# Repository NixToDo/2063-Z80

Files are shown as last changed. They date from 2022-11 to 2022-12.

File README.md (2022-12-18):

# Retro Z80 CPU Board

This project is a small changed copy of the great design from John Winans. I have added a J3A1 connector to get the IORQ_50, IORQ_60 and SIO_IEO from the PCB.

This project was designed to run CP/M 2.2 from an SD card.  It should be an attainable goal for anyone that can solder through-hole parts to assemble it. Note that J10 is an optional header that allows a Sparkfun SD card breakout board [DEV-13743](https://www.digikey.com/en/products/detail/sparkfun-electronics/DEV-13743/5881845) to used instead of soldering on the surface-mount SD socket part.

## Where to get Boards & Software

* You can order boards from any prototype PCB vendor.  For example, I show how you can order these boards from [JLCPCB](https://jlcpcb.com/) or [OSHPark](https://oshpark.com/) by uploading the gerber files found in the releases of this and the flash programmer projects as shown in this [Z80 Retro! - How To Order PC Boards](https://youtu.be/AUg_sbPnzn0) video on YouTube.
  - Gerber files for the CPU board: [2063-Z80-v3](https://github.com/johnwinans/2063-Z80/releases/download/v3/2063-Z80-gerbers.zip)
  - Gerber files for the FLASH programmer: [2065-Z80-programmer-v2](https://github.com/johnwinans/2065-Z80-programmer/releases/download/v2.0/2065-Z80-programmer-gerbers.zip) (This is used with a Raspberry PI to program the FLASH chip on the CPU board.)

* Software for this project can be found in my [2063-Z80-cpm](https://github.com/johnwinans/2063-Z80-cpm) repo.

* Note that the [FLASH programmer](https://github.com/johnwinans/2065-Z80-programmer) has been designed to work with a Raspberry PI in the event that you don't already own such programmer.  This companion programmer PCB should cost about $2 more when it is ordered at the same time as the CPU board from JLCPCB or other similar proto-board shops as shown in the [Z80 Retro! - How To Order PC Boards](https://youtu.be/AUg_sbPnzn0) video on YouTube.

## Links to Related Material

* A youtube playlist discussing this project and how to build your own can be found in [John's Basement](https://www.youtube.com/watch?v=oekucjDcNbA&list=PL3by7evD3F51Cf9QnsAEdgSQ4cz7HQZX5)
* A PDF version of the schematic can be found [here](2063-Z80.pdf).
* Here is the as-built [BOM](2063-Z80.md) with links to the datasheets for all the parts.
* Here is another [BOM](2063-Z80-sockets.md) with links to sockets for the chips.
* To configure a new PI for use with this programmer board as well as to develop Z80 code 
for the Z80 Retro board, see this [PI Setup Guide](https://github.com/johnwinans/raspberry-pi-install)
* More software for this project will be added as it evolves.

## Links to Related Datasheets Seen On YouTube

* [Z80 Datasheet PS0178](https://www.zilog.com/docs/z80/ps0178.pdf) with detailed timing diagrams.
* [Z80 User Manual UM0080](http://www.zilog.com/docs/z80/um0080.pdf) with detailed descriptions of each instruction.
* [Z80 CPU Peripherals User Manual UM0081](http://www.zilog.com/docs/z80/um0081.pdf) discusses the CTC and SIO.
* [Z80 Family Product Specifications Handbook - 1984](http://www.bitsavers.org/components/zilog/z80/Z80_Family_Product_Specifications_Handbook_Feb84.pdf) has nicer pictures of the SIO registers.
* [Wikipedia UART Article](https://en.wikipedia.org/wiki/Universal_asynchronous_receiver-transmitter)
* [AY-3-1015D UART Datasheet](https://rocelec.widen.net/view/pdf/bvesdj0cqf/GSIIS01845-1.pdf) (Has a discussion of the 16X bit-rate clock with diagrams etc. applicable to all UARTs.)

## Serial Port Cable Parts

* [How to make IDC cables](https://youtu.be/gZ420Z-8HuU) for the serial ports.
* [IDC 2x5 connectors](https://www.amazon.com/gp/product/B07S1NFG4S)
* [IDC D-SUB 9-pin connectors (Digikey)](https://www.digikey.com/en/products/detail/assmann-wsw-components/A-DSF-09LPIII-Z/924263)
* [IDC D-SUB 9-pin connectors (Amazon)](https://www.amazon.com/Uxcell-a15030600ux0494-Female-Connector-Ribbon/dp/B00YM41NTW)

## Parallel Port Cable Parts

* [IDC 2x13 connectors](https://www.amazon.com/gp/product/B07RXK96GV)
* [IDC D-SUB 25-pin connectors (Digikey)](https://www.digikey.com/en/products/detail/amphenol-icc-commercial-products/L17DBFRA25S/1972210)
* [IDC D-SUB 25-pin connectors (Amazon)](https://www.amazon.com/Fielect-Female-Adapter-Connector-Ribbon/dp/B082GMDNTS)

## Ribbon Cable

* [40-conductor (Amazon)](https://www.amazon.com/Eowpower-40Pin-40Way-Rainbow-Ribbon/dp/B079KQ6K3Y) - peel off a
 26-pin strip and a 10-pin strip to make one parallel and one serial cable (cut the 10-pin strip in half length-wise to make two serial cables.

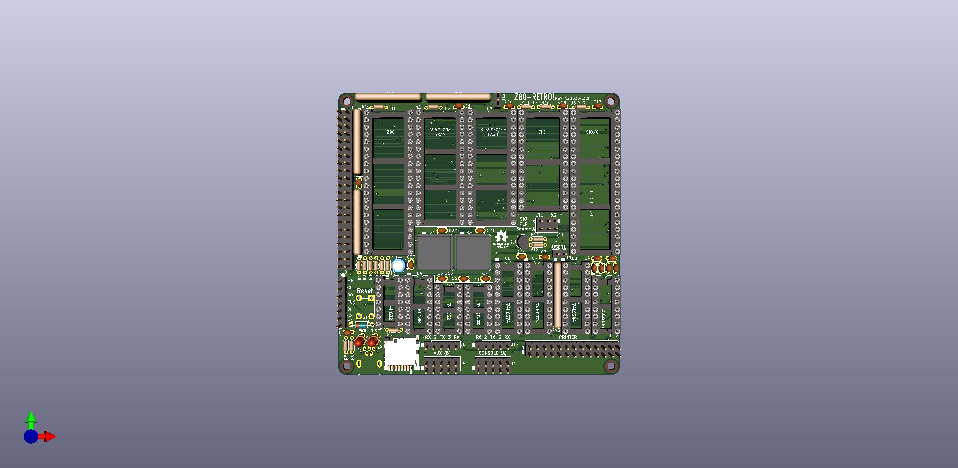
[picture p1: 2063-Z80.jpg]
PC Board Image Retro Z80 CPU Board Rev 2


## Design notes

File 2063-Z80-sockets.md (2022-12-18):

## IC Sockets

You can buy fancy expensive ones, or you can buy cheap ones.
I used the cheap ones.  

Alternately, you can just solder the chips into the PCB.

As a tinkerer, the thing that is wrong with that is that it makes it very hard to 
recycle/repurpose the chips for something else in the future.  And with the 2021
chip-shortage in full-force on as I type this, being able to recycle chips is 
VERY appealing!

Be honest with yourself before sinking more money into sockets than the cost of the chips 
that go into them.  I expect the cheap ones to last for at least a decade or two.  Cheap
sockets in my hobby projects from 30 years ago are still doing fine.

Gold plating is better than tin.  Machined pins (see the oscillator sockets) are better than
stamped spring-metal pins. 

Ref | Qty | Value | Digikey | Datasheet | Description
----|-----|-------|---------|-----------|------------
U1,U5 | 2 | Socket | AE10008-ND | http://www.assmann-wsw.com/uploads/datasheets/ASS_0810_CO.pdf | DIP-40
U2,U3 | 2 | Socket | 2057-ICS-632-T-ND | https://app.adam-tech.com/products/download/data_sheet/199581/ics-6xx-t-data-sheet.pdf | DIP-32
U4 | 1 | Socket | 2057-ICS-628-T-ND | https://app.adam-tech.com/products/download/data_sheet/199581/ics-6xx-t-data-sheet.pdf | DIP-28
U10,U13,U11 | 3 | Socket | 2057-ICS-314-T-ND | https://app.adam-tech.com/products/download/data_sheet/199582/ics-3xx-t-data-sheet.pdf | DIP-14
U9,U12 | 2 | Socket | 2057-ICS-316-T-ND | https://app.adam-tech.com/products/download/data_sheet/199582/ics-3xx-t-data-sheet.pdf | DIP-16
U6,U7,U8 | 3 | Socket | 2057-ICS-320-T-ND | https://app.adam-tech.com/products/download/data_sheet/199582/ics-3xx-t-data-sheet.pdf | DIP-20

# Sockets for the Oscillators

Metal can oscillators have wires for pins.  In my experience they tend to sit loosely in 
regular sockets and do better in machined-pin sockets.

For these 4-pin parts you have two options.  Either order a relatively expensive pair of 
sockets ready to solder in as-is or order a pair with extra pins and remove the ones you don't
want and then solder in. 

I went the latter route because I already had several 8-pin sockets on hand.

To remove the extra pins from the fully loaded sockets, use a small pliers to grab the pins 
to be removed from the bottom of the socket and push them out the top.

Look at the photos of each type and you'll see what I mean.

Ref | Qty | Value | Digikey | Datasheet | Description
----|-----|-------|---------|-----------|------------
X1,X2 | 2 | Socket | ED90427-ND | https://www.mill-max.com/catalog/download/2017-11:134.pdf | OSC-4 (a whopping $1.50 each!)
X1,X2 | 2 | Socket | AE10011-ND | http://www.assmann-wsw.com/uploads/datasheets/ASS_4852_CO.pdf | DIP-8 ($.50 each)

## Shorting Blocks

These are for selecting the clock sources for the SIO, user jumper, and 
RS-232 TX/RX pin number selection.

Ref | Qty | Value | Digikey | Datasheet | Description
----|-----|-------|---------|-----------|------------
J11,J9,J1,J8 | 7 | S9337-ND | https://s3.amazonaws.com/catalogspreads-pdf/PAGE128-129%20.100%20JUMPER.pdf | Shorting Block | Shorting Jumper

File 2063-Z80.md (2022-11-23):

# 2063-Z80.sch

## Wed Dec  1 16:48:16 2021

## Eeschema 5.1.5+dfsg1-2build2

## Component Count:84

Ref | Qty | Value | Digikey | Datasheet | Description
----|-----|-------|---------|-----------|------------
Z5U RM2,5 100n 50V             C1, C2, C3, C4, C5, C6, C7, C8, C9, C10, C11, C12, C13, C14, C15, C16, C21, C22, C23 | 19 | .1 | 399-9859-1-ND | https://api.kemet.com/component-edge/download/specsheet/C315C104M5U5TA7303.pdf | Unpolarized capacitor, small symbol
X7R 0805 100n 50V              C17 | 1 | .1 | 1276-1935-1-ND | https://www.mouser.com/datasheet/2/585/MLCC-1837944.pdf | Unpolarized capacitor, small symbol
X5R 0805 10µ 6,3V              C18 | 1 | 10uF | 1276-1298-1-ND | https://media.digikey.com/pdf/Data%20Sheets/Samsung%20PDFs/CL21A106MQFNNNE_Spec.pdf | Polarized capacitor, small US symbol
    RM2,54 10µ 25V                C19 | 1 | 10uF | P975-ND | https://industrial.panasonic.com/cdbs/www-data/pdf/RDF0000/ABA0000C1059.pdf | Polarized capacitor, small US symbol
X7R RM2,54 0,47µ 50V            C20 | 1 | .47 | 399-14039-1-ND | https://api.kemet.com/component-edge/download/datasheet/C315C474K5R5TA7303.pdf | Unpolarized capacitor, small symbol
X7R 0805 100n 50V              C24 | 1 | .1 | 1276-1935-1-ND | https://www.mouser.com/datasheet/2/585/MLCC-1837944.pdf | Unpolarized capacitor, small symbol
3mm LED rot 20mA               D1, D2 | 2 | LED_ALT | 1080-1122-ND | https://media.digikey.com/PDF/Data%20Sheets/Everlight%20PDFs/ds300034.pdf | Light emitting diode, filled shape
1N4148                         D3 | 1 | 1N914 | 1N4148FSCT-ND | http://www.vishay.com/docs/85622/1n914.pdf | 100V 0.3A Small Signal Fast Switching Diode, DO-35
                               H1, H2, H3, H4 | 4 | MountingHole |  |  | Mounting Hole without connection
Pinheader 1x5 pol              J1, J8 | 2 | Conn_01x05 | S1211EC-05-ND | https://media.digikey.com/PDF/Data%20Sheets/Sullins%20PDFs/xRxCzzzSxxN-RC_ST_11635-B.pdf | Generic connector, single row, 01x05, script generated (kicad-library-utils/schlib/autogen/connector/)
Micro SDcard DM3D-SF(41)       J2 | 1 | DM3D-SF(41) | H126097CT-ND (alternate: 114-00841-68-1-ND) | https://www.hirose.com/product/document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 | Micro SD Card Socket with card detection pins
Pinheader 2x20 pol             J3 | 1 | Conn_02x20 | S2011EC-20-ND | https://drawings-pdf.s3.amazonaws.com/11636.pdf | Generic connector, double row, 02x20, counter clockwise pin numbering scheme (similar to DIP packge numbering), script generated (kicad-library-utils/schlib/autogen/connector/)
Pinheader 2x5 pol              J4, J5 | 2 | Conn_02x05 | 1849-1002-ND |  | Generic connector, double row, 02x05, odd/even pin numbering scheme (row 1 odd numbers, row 2 even numbers), script generated (kicad-library-utils/schlib/autogen/connector/)
Mini USB Buchse 2172034-1      J6 | 1 | 0548190519 | A135698-ND | https://www.molex.com/pdm_docs/sd/548190519_sd.pdf | CONN RCPT USB2.0 MINI B 5P R/A
Pinheader 2x13 pol             J7 | 1 | Conn_02x13 | S2011EC-13-ND | https://drawings-pdf.s3.amazonaws.com/11636.pdf | Generic connector, double row, 02x13, top/bottom pin numbering scheme (row 1: 1...pins_per_row, row2: pins_per_row+1 ... num_pins), script generated (kicad-library-utils/schlib/autogen/connector/)
Pinheader 1x2 pol              J9, J12 | 2 | Conn_01x02 | S1011EC-02-ND | https://media.digikey.com/PDF/Data%20Sheets/Sullins%20PDFs/xRxCzzzSxxN-RC_ST_11635-B.pdf | Generic connector, single row, 01x02, script generated (kicad-library-utils/schlib/autogen/connector/)
Pinheader 1x7 pol              J10 | 1 | Conn_01x07 | S1011EC-07-ND | https://media.digikey.com/PDF/Data%20Sheets/Sullins%20PDFs/xRxCzzzSxxN-RC_ST_11635-B.pdf | Generic connector, single row, 01x07, script generated (kicad-library-utils/schlib/autogen/connector/)
Pinheader 2x3 pol              J11 | 1 | Conn_02x03 | 2057-PH2-06-UA-ND | https://app.adam-tech.com/products/download/data_sheet/202065/ph2-xx-ua-data-sheet.pdf | Generic connector, double row, 02x03, odd/even pin numbering scheme (row 1 odd numbers, row 2 even numbers), script generated (kicad-library-utils/schlib/autogen/connector/)
                               LOGO1 | 1 | OSHW_Logo |  |  | Open Hardware logo, small
                               LOGO2 | 1 | OSHW_Logo |  |  | Open Hardware logo, small
PN2222A                        Q1 | 1 | PN2222 | 1514-PN2222APBFREE-ND | https://my.centralsemi.com/datasheets/PN2221-2222A.PDF | NPN transistor, emitter/base/collector
2,7k 5% 1/8W axial             R1, R3, R5 | 3 | 2K7 | CF18JT2K70CT-ND | https://www.seielect.com/catalog/sei-cf_cfm.pdf | Resistor
4,7k 5% 1/8W axial             R2, R4, R6 | 3 | 4K7 | CF18JT4K70CT-ND | https://www.seielect.com/catalog/sei-cf_cfm.pdf | Resistor
10k 5% 1/8W axial              R7, R10, R13, R14 | 4 | 10K | CF18JT10K0CT-ND | https://www.seielect.com/catalog/sei-cf_cfm.pdf | Resistor
680 5% 1/8W axial              R8, R9 | 2 | 680 | CF18JT680RCT-ND‎ | https://www.seielect.com/catalog/sei-cf_cfm.pdf | Resistor
1k 5% 1/8W axial               R11, R12 | 2 | 1K | CF18JT1K00CT-ND‎ | https://www.seielect.com/catalog/sei-cf_cfm.pdf | Resistor
120 5% 1/8W axial              R15, R16 | 2 | 120 | CF18JT120RCT-ND | https://www.seielect.com/catalog/sei-cf_cfm.pdf | Resistor
10k SIL 8R                     RN1, RN2, RN3, RN4, RN5 | 5 | 10K | 4609X-101-103LF-ND‎ | https://www.bourns.com/docs/Product-Datasheets/4600x.pdf | 8 resistor network, star topology, bussed resistors, small symbol
Taster FSM4JH                  S1 | 1 | 1825910-6 | 450-1650-ND | https://www.te.com/commerce/DocumentDelivery/DDEController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 | SWITCH TACTILE SPST-NO 0.05A 24V
Z84C0010PEG                    U1 | 1 | Z80-CPU | 269-3898-ND | https://www.zilog.com/manage_directlink.php?filepath=docs/z80/um0080 | 8-bit General Purpose Microprocessor, DIP-40
AS6C4008-55PCN                 U2 | 1 | AS6C4008-55PCN | 1450-1178-5-ND‎ | https://www.alliancememory.com/wp-content/uploads/pdf/AS6C4008.pdf | 512K x 8 Low Power CMOS RAM, DIP-32
Vorhanden                      U3 | 1 | SST39SF010 | SST39SF010A-70-4C-PHE-ND‎ | https://ww1.microchip.com/downloads/en/DeviceDoc/20005022C.pdf | Silicon Storage Technology (SSF) 128k x 8 Flash ROM
Z84C3010PEG                    U4 | 1 | Z80-CTC | 269-3914-ND | http://www.zilog.com/docs/z80/ps0181.pdf | Z80 CTC DIP-28
Z84C4010PEG                    U5 | 1 | Z80-SIO-0 | 269-5062-ND‎ | http://www.zilog.com/docs/z80/ps0183.pdf | SCC Serial Communication Controller, DIP-40
74HC374                        U6, U7 | 2 | 74HC374 | 296-12806-5-ND | https://www.ti.com/lit/ds/symlink/cd74hct374.pdf | 8-bit Register, 3-state outputs
74LS244                        U8 | 1 | 74LS244 | 296-36148-5-ND | https://www.ti.com/lit/ds/symlink/sn74ls241.pdf | 8-bit Bus Buffer 3-State outputs
74HC138                        U9 | 1 | 74HC138 | 296-SN74HC138AN-ND | https://www.ti.com/lit/ds/symlink/sn54hc138.pdf | Decoder 3 to 8 active low outputs
74HC32                         U10, U13 | 2 | 74HC32 | 296-12803-5-ND | https://www.ti.com/lit/ds/symlink/cd74hc32.pdf | Quad 2-input OR
74HCT132                       U11 | 1 | 74HCT132 | 296-2090-5-ND | https://www.ti.com/lit/ds/symlink/cd74hc132.pdf | Quad 2-input NAND Schmitt trigger
ICL3232CPZ alt: MAX3232        U12 | 1 | ICL3232CPZ | ICL3232CPZ-ND‎ | https://www.renesas.com/us/en/document/dst/icl3221-icl3222-icl3223-icl3232-icl3241-icl3243-datasheet | 3.0V to 5.5V, Low-Power, up to 1Mbps, True RS-232 Transceivers Using Four 0.1μF External Capacitors
NCP1117ST33T3G                 U20 | 1 | LM1117-3.3 | NCP1117ST33T3GOSCT-ND | https://www.onsemi.com/pdf/datasheet/ncp1117-d.pdf | 800mA Low-Dropout Linear Regulator, 1.8V fixed output, TO-220/TO-252/TO-263/SOT-223
ACH-10.000MHZ-EK               X1 | 1 | ACH-10.000MHZ-EK | 535-9167-5-ND | https://abracon.com/Oscillators/ACH.pdf | Crystal Clock Oscillator, DIP8-style metal package
ECS-2100A-018                  X2 | 1 | ECS-2100A-018 | XC231-ND‎ | https://ecsxetal.com/store/pdf/ecs_2100.pdf | Crystal Clock Oscillator, DIP8-style metal package

40 Pin                         U1,U5 | 2 | Socket | AE10008-ND | http://www.assmann-wsw.com/uploads/datasheets/ASS_0810_CO.pdf | DIP-40
32 Pin                         U2,U3 | 2 | Socket | 2057-ICS-632-T-ND | https://app.adam-tech.com/products/download/data_sheet/199581/ics-6xx-t-data-sheet.pdf | DIP-32
28 Pin                         U4 | 1 | Socket | 2057-ICS-628-T-ND | https://app.adam-tech.com/products/download/data_sheet/199581/ics-6xx-t-data-sheet.pdf | DIP-28
14 Pin                         U10,U13,U11 | 3 | Socket | 2057-ICS-314-T-ND | https://app.adam-tech.com/products/download/data_sheet/199582/ics-3xx-t-data-sheet.pdf | DIP-14
16 Pin                         U9,U12 | 2 | Socket | 2057-ICS-316-T-ND | https://app.adam-tech.com/products/download/data_sheet/199582/ics-3xx-t-data-sheet.pdf | DIP-16
20 Pin                         U6,U7,U8 | 3 | Socket | 2057-ICS-320-T-ND | https://app.adam-tech.com/products/download/data_sheet/199582/ics-3xx-t-data-sheet.pdf | DIP-20

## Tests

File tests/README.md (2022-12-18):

# Basic test applications for the Z80 Retro board.

These applications require the use of `z80asm`.  You can install it like this:

	sudo apt install z80asm

Assemble these test applications like this:

	make world

Download them into the FLASH by using the `flash` programming application in the 
[2065-Z80-programmer](https://github.com/johnwinans/2065-Z80-programmer/tree/master/pi) 
project in github.  If you cloned the 2065-Z80-programmer project into your
home directory and built it on your PI then you can program these files like this:

	~/2065-Z80-programmer/pi/flash < blinky1.bin

## Test Programs

### blinky1.asm
Flash the SD card select LED.  This runs entirely from the FLASH (does not use SRAM).

### blinky2.asm
Flash the SD card select LED.  This copies itself from the FLASH into the SRAM and then runs from there.

### blinky3.asm
Flash the SD card select LED and at the same time, count on the printer port data lines.

### hello_sio1.asm
Test the SIO ports in polled mode.

### hello_sio2.asm
Test the SIO ports in IRQ mode.

### hello_ctc2.asm
Test the CTC with IRQs and print an 'uptime' counter using the SIO.

## bank_select.asm
Test the SRAM blank select logic by padding and dumping regions of memory in different banks.

## hello_lpt.asm
Test the printer port by priting a 'hello world' type message.

## hello_lpt2.asm
Test the printer port by priting gaudy banners.

## io.asm
Equates for the IO ports on the Z80 Retro! board.

## sio.asm
Simple driver for the SIO.

## hexdump.asm
A library to print a memory hex dump.

## ctc.asm
Simple driver for the CTC.

## lpt.asm
Simple driver for the printer.

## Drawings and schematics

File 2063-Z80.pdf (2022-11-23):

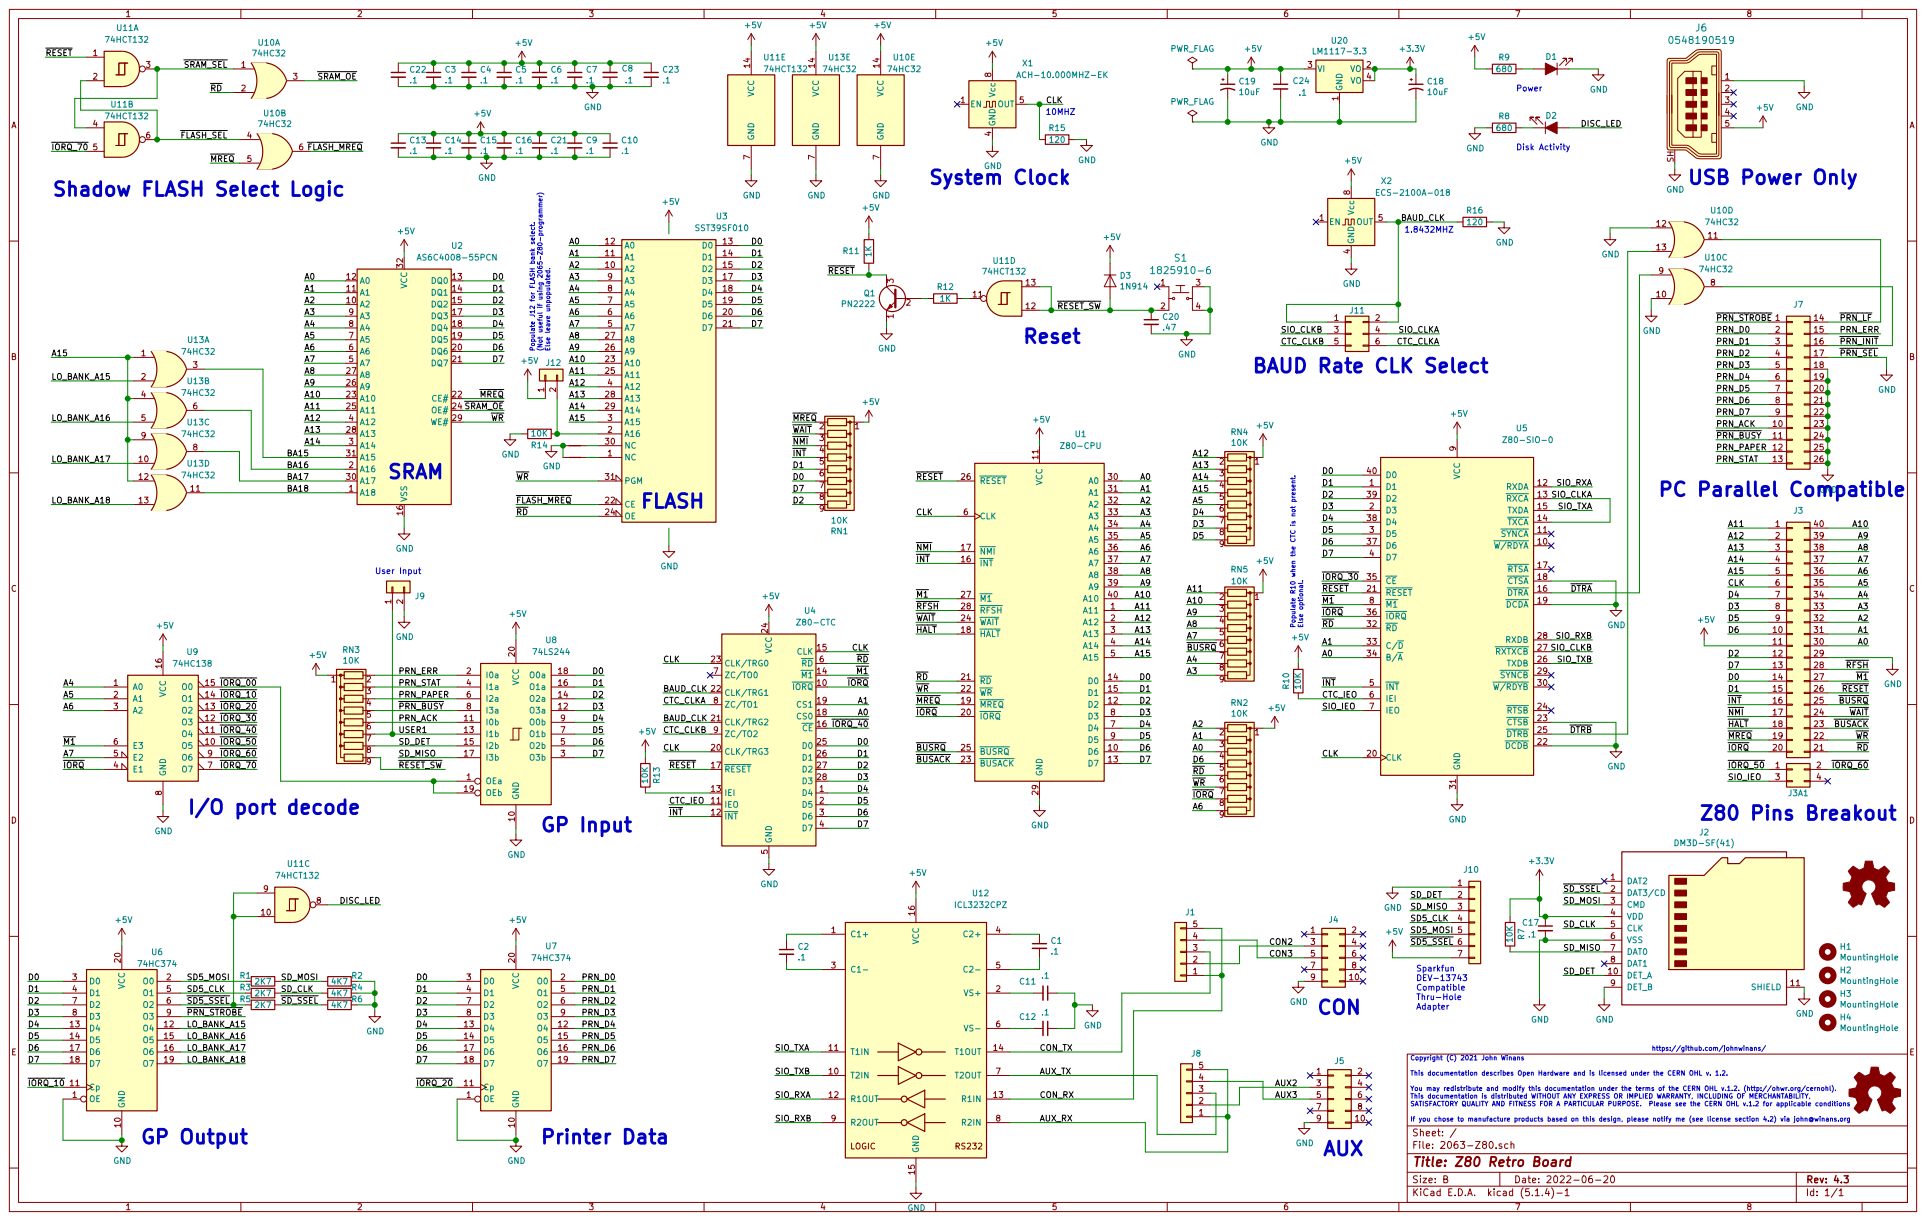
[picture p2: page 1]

If you chose to manufacture products based on this design, please notify me (see license section 4.2) via john@winans.org USB Power Only

Shadow FLASH Select Logic

Disk Activity Populate R10 when the CTC is not present. Else optional.

BAUD Rate CLK Select

5 | PRN_ACK

Sparkfun DEV-13743 Compatible Thru-Hole Adapter

https://github.com/johnwinans/ GP Output

Copyright (C) 2021 John Winans This documentation describes Open Hardware and is licensed under the CERN OHL v. 1.2. You may redistribute and modify this documentation under the terms of the CERN OHL v.1.2. (http://ohwr.org/cernohl). This documentation is distributed WITHOUT ANY EXPRESS OR IMPLIED WARRANTY, INCLUDING OF MERCHANTABILITY, SATISFACTORY QUALITY AND FITNESS FOR A PARTICULAR PURPOSE. Please see the CERN OHL v.1.2 for applicable conditions

File: 2063-Z80.sch Sheet: /
Id: 1/1 Title: Z80 Retro Board

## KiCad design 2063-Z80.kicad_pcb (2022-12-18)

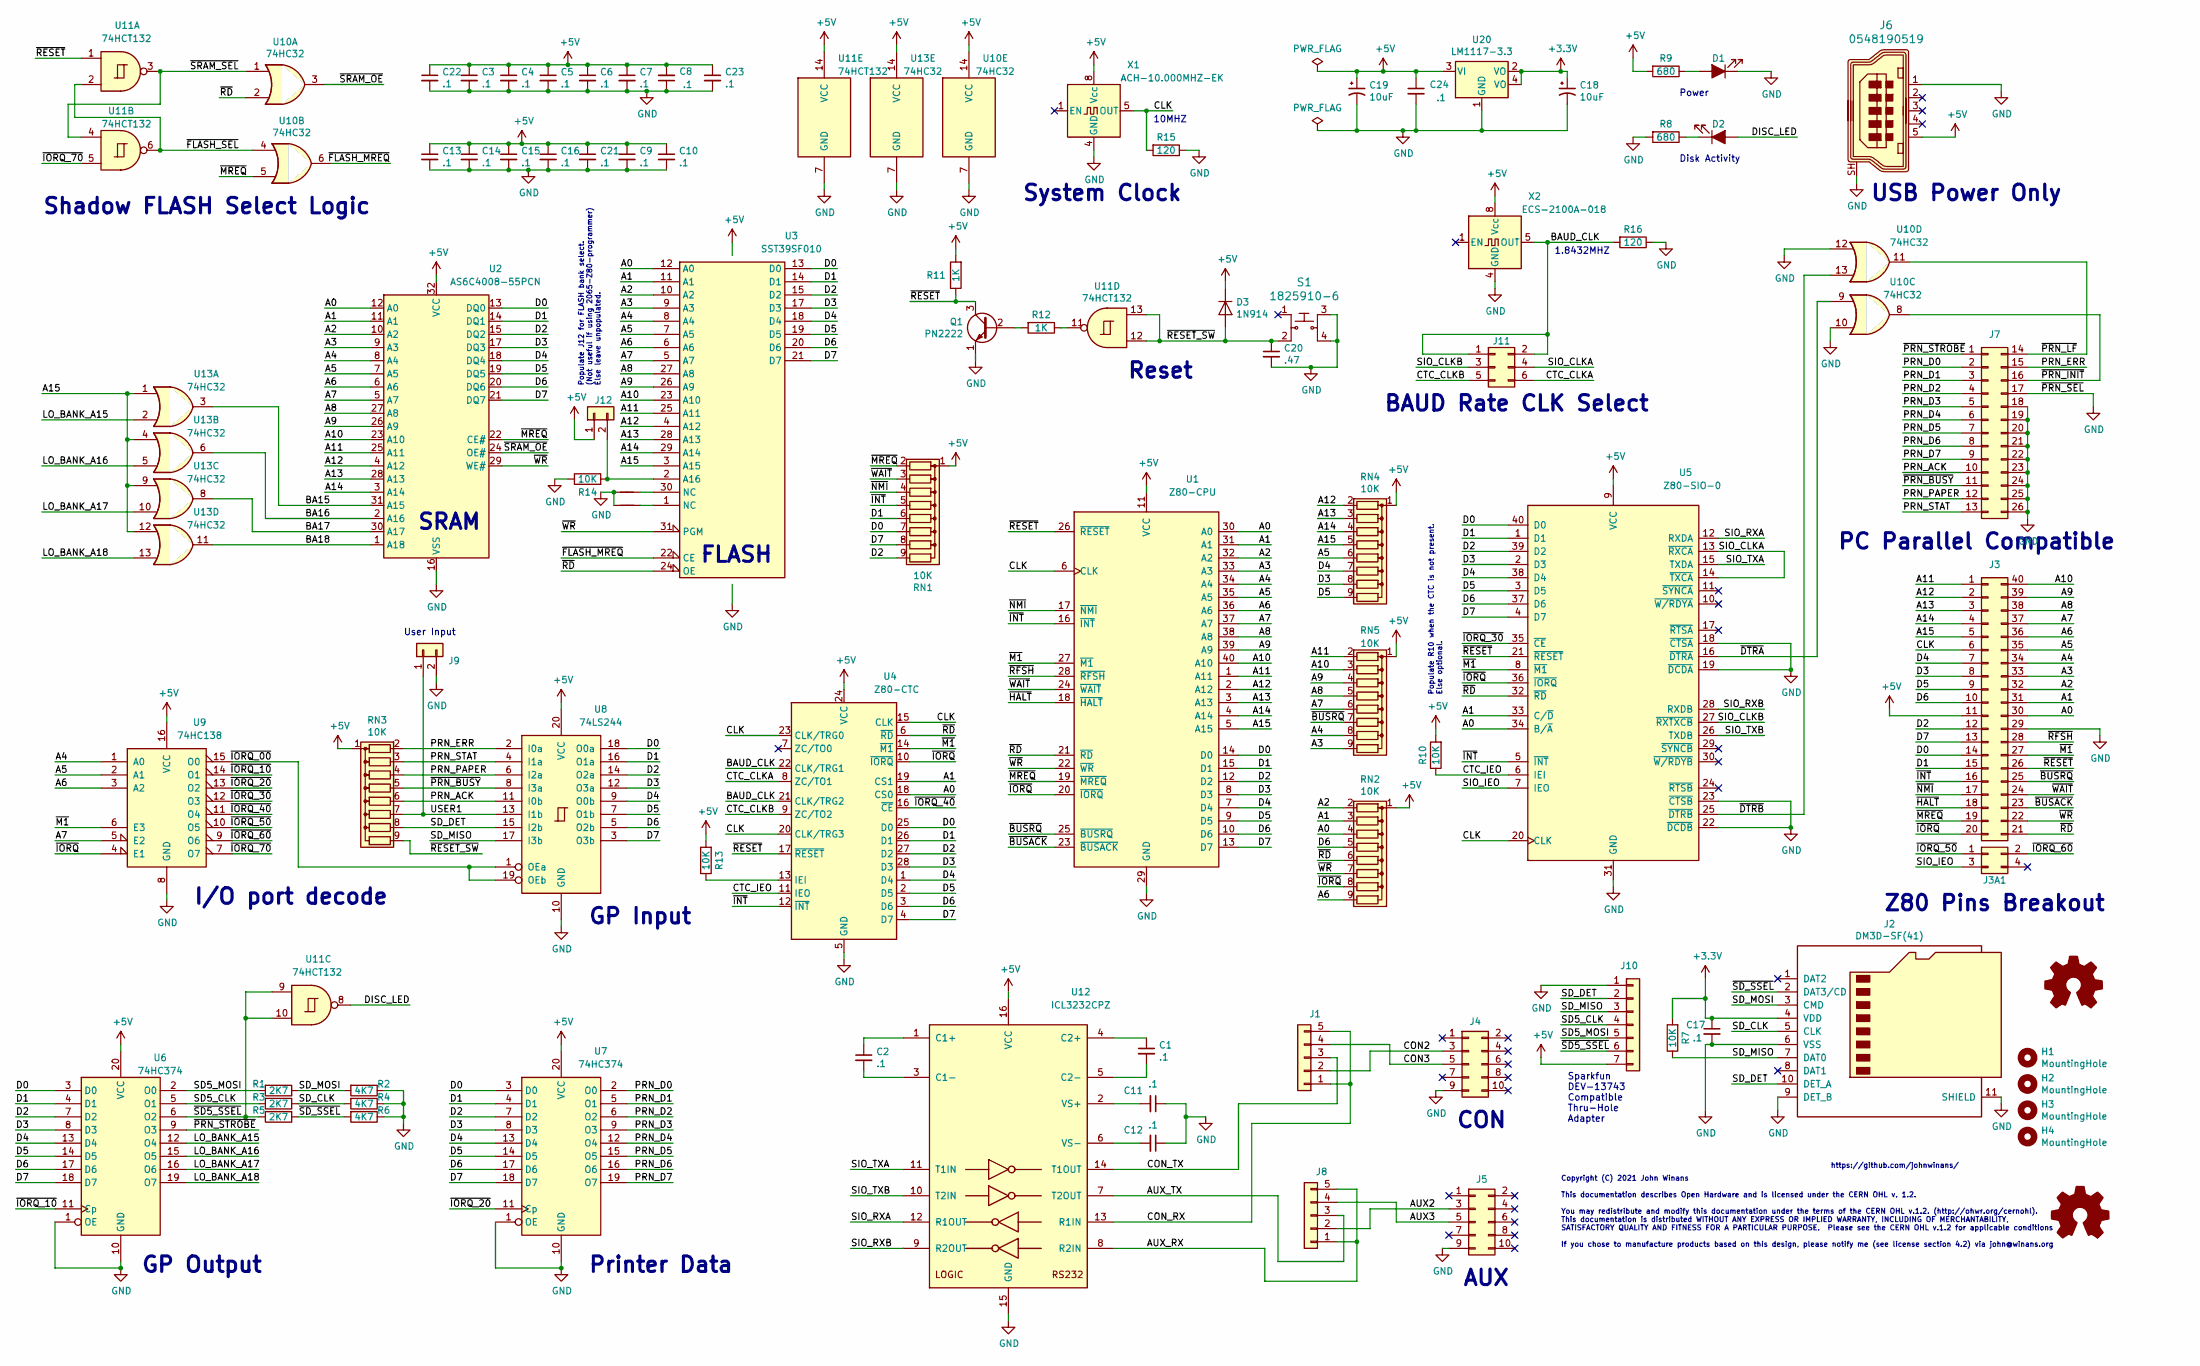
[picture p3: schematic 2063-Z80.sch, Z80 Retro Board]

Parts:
C1, C2, C3, C4, C5, C6, C7, C8, C9, C10, C11, C12, C13, C14, C15, C16, C21, C22, C23: .1; C_Disc_D3.0mm_W2.0mm_P2.50mm; MPN ‎C315C104M5U5TA7303‎; Digi-Key_PN 399-9859-1-ND
C17: .1; C_0805_2012Metric_Pad1.18x1.45mm_HandSolder; MPN CL10B104KB8NNWC; Digi-Key_PN 1276-1935-1-ND
C18: 10uF; C_0805_2012Metric_Pad1.18x1.45mm_HandSolder; MPN CL21A106MQFNNNE; Digi-Key_PN 1276-1298-1-ND
C19: 10uF; CP_Radial_D5.0mm_P2.50mm; MPN ECE-A1EKS100; Digi-Key_PN P975-ND
C20: .47; C_Disc_D3.0mm_W2.0mm_P2.50mm; MPN C315C474K5R5TA7303; Digi-Key_PN 399-14039-1-ND
C24: .1; C_0805_2012Metric_Pad1.15x1.40mm_HandSolder; MPN CL10B104KB8NNWC; Digi-Key_PN 1276-1935-1-ND
D1, D2: LED_ALT; LED_D3.0mm; MPN MV57640; Digi-Key_PN 1080-1122-ND
D3: 1N914; D_DO-35_SOD27_P7.62mm_Horizontal; MPN 1N4148TR; Digi-Key_PN 1N4148FSCT-ND
H1, H2, H3, H4: MountingHole; MountingHole_2.7mm
J1, J8: Conn_01x05; PinHeader_1x05_P2.54mm_Vertical; MPN PRPC005SFAN-RC; Digi-Key_PN S1211EC-05-ND
J2: DM3D-SF(41); microSD_HC_Hirose_DM3D-SF; MPN ‎DM3D-SF(41)‎; Digi-Key_PN H126097CT-ND (alternate: 114-00841-68-1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
J3: Conn_02x20; PinHeader_2x20_P2.54mm_Vertical_counterclock; MPN PRPC020DAAN-RC; Digi-Key_PN S2011EC-20-ND
J3A1: Conn_02x02_Odd_Even; PinHeader_2x02_P2.54mm_Vertical
J4, J5: Conn_02x05; PinHeader_2x05_P2.54mm_Vertical; MPN PR20205VBDN; Digi-Key_PN 1849-1002-ND
J6: 0548190519; USB_Mini_B_Female_548190519; MPN 0548190519; Digi-Key_PN A135698-ND
J7: Conn_02x13; PinHeader_2x13_P2.54mm_Top_Bottom; MPN PRPC013DAAN-RC; Digi-Key_PN S2011EC-13-ND
J9, J12: Conn_01x02; PinHeader_1x02_P2.54mm_Vertical; MPN PRPC002SAAN-RC; Digi-Key_PN S1011EC-02-ND
J10: Conn_01x07; PinHeader_1x07_P2.54mm_Vertical; MPN PRPC007SAAN-RC; Digi-Key_PN S1011EC-07-ND
J11: Conn_02x03; PinHeader_2x03_P2.54mm_Vertical; MPN PH2-06-UA; Digi-Key_PN 2057-PH2-06-UA-ND
LOGO1: OSHW_Logo; OSHW-Logo_11.4x12mm_SilkScreen
LOGO2: OSHW_Logo; OSHW-Logo_5.7x6mm_SilkScreen
NT1, NT2: Net-Tie_2; NetTie-2_SMD_Pad0.5mm
Q1: PN2222; TO-92L; MPN PN2222A PBFREE; Digi-Key_PN 1514-PN2222APBFREE-ND
R1, R3, R5: 2K7; R_Axial_DIN0204_L3.6mm_D1.6mm_P5.08mm_Horizontal; MPN ‎CF18JT2K70‎; Digi-Key_PN CF18JT2K70CT-ND
R2, R4, R6: 4K7; R_Axial_DIN0204_L3.6mm_D1.6mm_P5.08mm_Horizontal; MPN ‎CF18JT4K70‎; Digi-Key_PN CF18JT4K70CT-ND
R7, R10, R13, R14: 10K; R_Axial_DIN0204_L3.6mm_D1.6mm_P5.08mm_Horizontal; MPN CF18JT10K0; Digi-Key_PN CF18JT10K0CT-ND
R8, R9: 680; R_Axial_DIN0204_L3.6mm_D1.6mm_P5.08mm_Horizontal; MPN ‎CF18JT680R‎; Digi-Key_PN CF18JT680RCT-ND‎
R11, R12: 1K; R_Axial_DIN0204_L3.6mm_D1.6mm_P5.08mm_Horizontal; MPN ‎CF18JT1K00‎; Digi-Key_PN CF18JT1K00CT-ND‎
R15, R16: 120; R_Axial_DIN0204_L3.6mm_D1.6mm_P5.08mm_Horizontal; MPN CF18JT120R; Digi-Key_PN CF18JT120RCT-ND
RN1, RN2, RN3, RN4, RN5: 10K; R_Array_SIP9; MPN ‎4609X-101-103LF‎; Digi-Key_PN 4609X-101-103LF-ND‎
S1: 1825910-6; Switch_Tactile_THT_6x6mm; MPN 1825910-6; Digi-Key_PN 450-1650-ND
U1: Z80-CPU; DIP-40_W15.24mm_Socket; MPN Z84C0010PEG‎; Digi-Key_PN 269-3898-ND
U2: AS6C4008-55PCN; DIP-32_W15.24mm_Socket; MPN AS6C4008-55PIN; Digi-Key_PN 1450-1178-5-ND‎
U3: SST39SF010; DIP-32_W15.24mm_Socket; MPN SST39SF010A-70-4C-PHE; Digi-Key_PN SST39SF010A-70-4C-PHE-ND‎
U4: Z80-CTC; DIP-28_W15.24mm_Socket; MPN Z84C3010PEG‎; Digi-Key_PN 269-3914-ND
U5: Z80-SIO-0; DIP-40_W15.24mm_Socket; MPN Z84C4010PEG‎; Digi-Key_PN 269-5062-ND‎
U6, U7: 74HC374; DIP-20_W7.62mm_Socket; MPN CD74HC374E; Digi-Key_PN 296-12806-5-ND
U8: 74LS244; DIP-20_W7.62mm_Socket; MPN SN74LS244NE4; Digi-Key_PN 296-36148-5-ND
U9: 74HC138; DIP-16_W7.62mm_Socket; MPN SN74HC138AN; Digi-Key_PN 296-SN74HC138AN-ND
U10, U13: 74HC32; DIP-14_W7.62mm_Socket; MPN CD74HC32E; Digi-Key_PN 296-12803-5-ND
U11: 74HCT132; DIP-14_W7.62mm_Socket; MPN CD74HCT132E; Digi-Key_PN 296-2090-5-ND
U12: ICL3232CPZ; DIP-16_W7.62mm_Socket; MPN ‎ICL3232CPZ‎; Digi-Key_PN ICL3232CPZ-ND‎
U20: LM1117-3.3; SOT-223; MPN NCP1117ST33T3G; Digi-Key_PN NCP1117ST33T3GOSCT-ND
X1: ACH-10.000MHZ-EK; Oscillator_DIP-8_combo; MPN ACH-10.000MHZ-EK; Digi-Key_PN 535-9167-5-ND
X2: ECS-2100A-018; Oscillator_DIP-8_combo; MPN ‎ECS-2100A-018‎; Digi-Key_PN XC231-ND‎

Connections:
+3V3: C17.1, C18.1, J2.4 (VDD), R7.2, U20.2 (VO), U20.4 (VO)
+5V: C3.1, C4.1, C5.1, C6.1, C7.1, C8.2, C9.1, C10.1, C13.1, C14.1, C15.1, C16.1, C19.1, C21.1, C22.1, C23.1, C24.1, D3.1 (K), J3.11, J6.5, J10.7, J12.1, R9.2, R10.2, R11.2, R13.2, RN1.1 (common), RN2.1 (common), RN3.1 (common), RN4.1 (common), RN5.1 (common), U1.11 (VCC), U2.32 (VCC), U3.32 (VCC), U4.24 (VCC), U5.9 (VCC), U6.20 (VCC), U7.20 (VCC), U8.20 (VCC), U9.16 (VCC), U10.14 (VCC), U11.14 (VCC), U12.16 (VCC), U13.14 (VCC), U20.3 (VI), X1.8 (Vcc), X2.8 (Vcc)
/A0: J3.30, RN2.4 (R3), U1.30 (A0), U2.12 (A0), U3.12 (A0), U4.18 (CS0), U5.34 (B/~A)
/A1: J3.31, RN2.3 (R2), U1.31 (A1), U2.11 (A1), U3.11 (A1), U4.19 (CS1), U5.33 (C/~D)
/A2: J3.32, RN2.2 (R1), U1.32 (A2), U2.10 (A2), U3.10 (A2)
/A3: J3.33, RN5.9 (R8), U1.33 (A3), U2.9 (A3), U3.9 (A3)
/A4: J3.34, RN5.8 (R7), U1.34 (A4), U2.8 (A4), U3.8 (A4), U9.1 (A0)
/A5: J3.35, RN4.6 (R5), U1.35 (A5), U2.7 (A5), U3.7 (A5), U9.2 (A1)
/A6: J3.36, RN2.9 (R8), U1.36 (A6), U2.6 (A6), U3.6 (A6), U9.3 (A2)
/A7: J3.37, RN5.6 (R5), U1.37 (A7), U2.5 (A7), U3.5 (A7), U9.5 (E2)
/A8: J3.38, RN5.5 (R4), U1.38 (A8), U2.27 (A8), U3.27 (A8)
/A9: J3.39, RN5.4 (R3), U1.39 (A9), U2.26 (A9), U3.26 (A9)
/A10: J3.40, RN5.3 (R2), U1.40 (A10), U2.23 (A10), U3.23 (A10)
/A11: J3.1, RN5.2 (R1), U1.1 (A11), U2.25 (A11), U3.25 (A11)
/A12: J3.2, RN4.2 (R1), U1.2 (A12), U2.4 (A12), U3.4 (A12)
/A13: J3.3, RN4.3 (R2), U1.3 (A13), U2.28 (A13), U3.28 (A13)
/A14: J3.4, RN4.4 (R3), U1.4 (A14), U2.3 (A14), U3.29 (A14)
/A15: J3.5, RN4.5 (R4), U1.5 (A15), U3.3 (A15), U13.1, U13.4, U13.9, U13.12
/AUX2: J5.3, J8.2
/AUX3: J5.5, J8.4
/AUX_RX: J8.1, J8.5, U12.8 (R2IN)
/AUX_TX: J8.3, U12.7 (T2OUT)
/BA15: U2.31 (A15), U13.3
/BA16: U2.2 (A16), U13.6
/BA17: U2.30 (A17), U13.8
/BA18: U2.1 (A18), U13.11
/BAUD_CLK: J11.1, J11.2, R16.2, U4.21 (CLK/TRG2), U4.22 (CLK/TRG1), X2.5 (OUT)
/CLK: J3.6, R15.2, U1.6 (CLK), U4.15 (CLK), U4.20 (CLK/TRG3), U4.23 (CLK/TRG0), U5.20 (CLK), X1.5 (OUT)
/CON2: J1.2, J4.3
/CON3: J1.4, J4.5
/CON_RX: J1.1, J1.5, U12.13 (R1IN)
/CON_TX: J1.3, U12.14 (T1OUT)
/CTC_CLKA: J11.6, U4.8 (ZC/TO1)
/CTC_CLKB: J11.5, U4.9 (ZC/TO2)
/CTC_IEO: R10.1, U4.11 (IEO), U5.6 (IEI)
/D0: J3.14, RN1.7 (R6), U1.14 (D0), U2.13 (DQ0), U3.13 (D0), U4.25 (D0), U5.40 (D0), U6.3 (D0), U7.3 (D0), U8.18 (O0a)
/D1: J3.15, RN1.6 (R5), U1.15 (D1), U2.14 (DQ1), U3.14 (D1), U4.26 (D1), U5.1 (D1), U6.4 (D1), U7.4 (D1), U8.16 (O1a)
/D2: J3.12, RN1.9 (R8), U1.12 (D2), U2.15 (DQ2), U3.15 (D2), U4.27 (D2), U5.39 (D2), U6.7 (D2), U7.7 (D2), U8.14 (O2a)
/D3: J3.8, RN4.8 (R7), U1.8 (D3), U2.17 (DQ3), U3.17 (D3), U4.28 (D3), U5.2 (D3), U6.8 (D3), U7.8 (D3), U8.12 (O3a)
/D4: J3.7, RN4.7 (R6), U1.7 (D4), U2.18 (DQ4), U3.18 (D4), U4.1 (D4), U5.38 (D4), U6.13 (D4), U7.13 (D4), U8.9 (O0b)
/D5: J3.9, RN4.9 (R8), U1.9 (D5), U2.19 (DQ5), U3.19 (D5), U4.2 (D5), U5.3 (D5), U6.14 (D5), U7.14 (D5), U8.7 (O1b)
/D6: J3.10, RN2.5 (R4), U1.10 (D6), U2.20 (DQ6), U3.20 (D6), U4.3 (D6), U5.37 (D6), U6.17 (D6), U7.17 (D6), U8.5 (O2b)
/D7: J3.13, RN1.8 (R7), U1.13 (D7), U2.21 (DQ7), U3.21 (D7), U4.4 (D7), U5.4 (D7), U6.18 (D7), U7.18 (D7), U8.3 (O3b)
/DISC_LED: D2.2 (A), U11.8
/LO_BANK_A15: U6.12 (O4), U13.2
/LO_BANK_A16: U6.15 (O5), U13.5
/LO_BANK_A17: U6.16 (O6), U13.10
/LO_BANK_A18: U6.19 (O7), U13.13
/PRN_ACK: J7.10, RN3.6 (R5), U8.11 (I0b)
/PRN_D0: J7.2, U7.2 (O0)
/PRN_D1: J7.3, U7.5 (O1)
/PRN_D2: J7.4, U7.6 (O2)
/PRN_D3: J7.5, U7.9 (O3)
/PRN_D4: J7.6, U7.12 (O4)
/PRN_D5: J7.7, U7.15 (O5)
/PRN_D6: J7.8, U7.16 (O6)
/PRN_D7: J7.9, U7.19 (O7)
/PRN_ERR: J7.15, RN3.2 (R1), U8.2 (I0a)
/PRN_PAPER: J7.12, RN3.4 (R3), U8.6 (I2a)
/PRN_STAT: J7.13, RN3.3 (R2), U8.4 (I1a)
/SD5_CLK: J10.4, R3.2, U6.5 (O1)
/SD5_MOSI: J10.5, R1.2, U6.2 (O0)
/SD_CLK: J2.5 (CLK), R3.1, R4.2
/SD_DET: J2.10 (DET_A), J10.2, RN3.8 (R7), U8.15 (I2b)
/SD_MISO: J2.7 (DAT0), J10.3, R7.1, U8.17 (I3b)
/SD_MOSI: J2.3 (CMD), R1.1, R2.2
/SIO_CLKA: J11.4, U5.13 (~RXCA), U5.14 (~TXCA)
/SIO_CLKB: J11.3, U5.27 (~RXTXCB)
/SIO_IEO: J3A1.3, U5.7 (IEO)
/SIO_RXA: U5.12 (RXDA), U12.12 (R1OUT)
/SIO_RXB: U5.28 (RXDB), U12.9 (R2OUT)
/SIO_TXA: U5.15 (TXDA), U12.11 (T1IN)
/SIO_TXB: U5.26 (TXDB), U12.10 (T2IN)
/USER1: J9.1, RN3.7 (R6), U8.13 (I1b)
/~BUSACK: J3.23, U1.23 (~BUSACK~)
/~BUSRQ: J3.25, RN5.7 (R6), U1.25 (~BUSRQ~)
/~DTRA: U5.16 (~DTRA), U10.9
/~DTRB: U5.25 (~DTRB), U10.13
/~FLASH_MREQ: U3.22 (CE), U10.6
/~FLASH_SEL: U10.4, U11.2, U11.6
/~HALT: J3.18, U1.18 (~HALT~)
/~INT: J3.16, RN1.5 (R4), U1.16 (~INT~), U4.12 (~INT), U5.5 (~INT)
/~IORQ: J3.20, RN2.8 (R7), U1.20 (~IORQ~), U4.10 (~IORQ), U5.36 (~IORQ), U9.4 (E1)
/~IORQ_00: U8.1 (OEa), U8.19 (OEb), U9.15 (O0)
/~IORQ_10: U6.11 (Cp), U9.14 (O1)
/~IORQ_20: U7.11 (Cp), U9.13 (O2)
/~IORQ_30: U5.35 (~CE), U9.12 (O3)
/~IORQ_40: U4.16 (~CE), U9.11 (O4)
/~IORQ_50: J3A1.1, U9.10 (O5)
/~IORQ_60: J3A1.2, U9.9 (O6)
/~IORQ_70: U9.7 (O7), U11.5
/~M1: J3.27, U1.27 (~M1~), U4.14 (~M1), U5.8 (~M1), U9.6 (E3)
/~MREQ: J3.19, RN1.2 (R1), U1.19 (~MREQ~), U2.22 (CE#), U10.5
/~NMI: J3.17, RN1.4 (R3), U1.17 (~NMI~)
/~PRN_BUSY: J7.11, RN3.5 (R4), U8.8 (I3a)
/~PRN_INIT: J7.16, U10.8
/~PRN_LF: J7.14, U10.11
/~PRN_STROBE: J7.1, U6.9 (O3)
/~RD: J3.21, RN2.6 (R5), U1.21 (~RD~), U3.24 (OE), U4.6 (~RD), U5.32 (~RD), U10.2
/~RESET: J3.26, Q1.3 (C), R11.1, U1.26 (~RESET~), U4.17 (~RESET), U5.21 (~RESET), U11.1
/~RESET_SW: C20.1, D3.2 (A), RN3.9 (R8), S1.2, U11.12, U11.13
/~RFSH: J3.28, U1.28 (~RFSH~)
/~SD5_SSEL: J10.6, R5.2, U6.6 (O2), U11.9, U11.10
/~SD_SSEL: J2.2 (DAT3/CD), R5.1, R6.2
/~SRAM_OE: U2.24 (OE#), U10.3
/~SRAM_SEL: U10.1, U11.3, U11.4
/~WAIT: J3.24, RN1.3 (R2), U1.24 (~WAIT~)
/~WR: J3.22, RN2.7 (R6), U1.22 (~WR~), U2.29 (WE#), U3.31 (PGM)
GND: C3.2, C4.2, C5.2, C6.2, C7.2, C8.1, C9.2, C10.2, C11.1, C12.1, C13.2, C14.2, C15.2, C16.2, C17.2, C18.2, C19.2, C20.2, C21.2, C22.2, C23.2, C24.2, D1.1 (K), J2.6 (VSS), J2.9 (DET_B), J2.11 (SHIELD), J3.29, J4.9, J5.9, J6.1, J6.SH, J7.17, J7.18, J7.19, J7.20, J7.21, J7.22, J7.23, J7.24, J7.25, J7.26, J9.2, J10.1, NT1.1, NT2.1, Q1.1 (E), R2.1, R4.1, R6.1, R8.2, R14.1, R15.1, R16.1, S1.3, S1.4, U1.29 (GND), U2.16 (VSS), U3.16 (GND), U4.5 (GND), U5.18 (~CTSA), U5.19 (~DCDA), U5.22 (~DCDB), U5.23 (~CTSB), U5.31 (GND), U6.1 (OE), U6.10 (GND), U7.1 (OE), U7.10 (GND), U8.10 (GND), U9.8 (GND), U10.7 (GND), U10.10, U10.12, U11.7 (GND), U12.15 (GND), U13.7 (GND), U20.1 (GND), X1.4 (GND), X2.4 (GND)
unnamed: C1.1, U12.4 (C2+)
unnamed: C1.2, U12.5 (C2-)
unnamed: C2.1, U12.1 (C1+)
unnamed: C2.2, U12.3 (C1-)
unnamed: C11.2, U12.2 (VS+)
unnamed: C12.2, U12.6 (VS-)
unnamed: D1.2 (A), R9.1
unnamed: D2.1 (K), R8.1
unnamed: J12.2, R14.2, U3.2 (A16)
unnamed: NT1.2, U3.30 (NC)
unnamed: NT2.2, U3.1 (NC)
unnamed: Q1.2 (B), R12.2
unnamed: R12.1, U11.11
unnamed: R13.1, U4.13 (IEI)

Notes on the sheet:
Disk Activity
Power
USB Power Only
Z80 Pins Breakout
Shadow FLASH Select Logic
FLASH
SRAM
GP Input
GP Output
Printer Data
PC Parallel Compatible
1.8432MHZ
I/O port decode
CON
AUX
Copyright (C) 2021 John Winans This documentation describes Open Hardware and is licensed under the CERN OHL v. 1.2. You may redistribute and modify this documentation under the terms of the CERN OHL v.1.2. (http://ohwr.org/cernohl). This documentation is distributed WITHOUT ANY EXPRESS OR IMPLIED 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
Reset
10MHZ
https://github.com/johnwinans/
Sparkfun DEV-13743 Compatible Thru-Hole Adapter
BAUD Rate CLK Select
System Clock
Populate R10 when the CTC is not present. Else optional.
User Input
Populate J12 for FLASH bank select. (Not useful if using 2065-Z80-programmer) Else leave unpopulated.

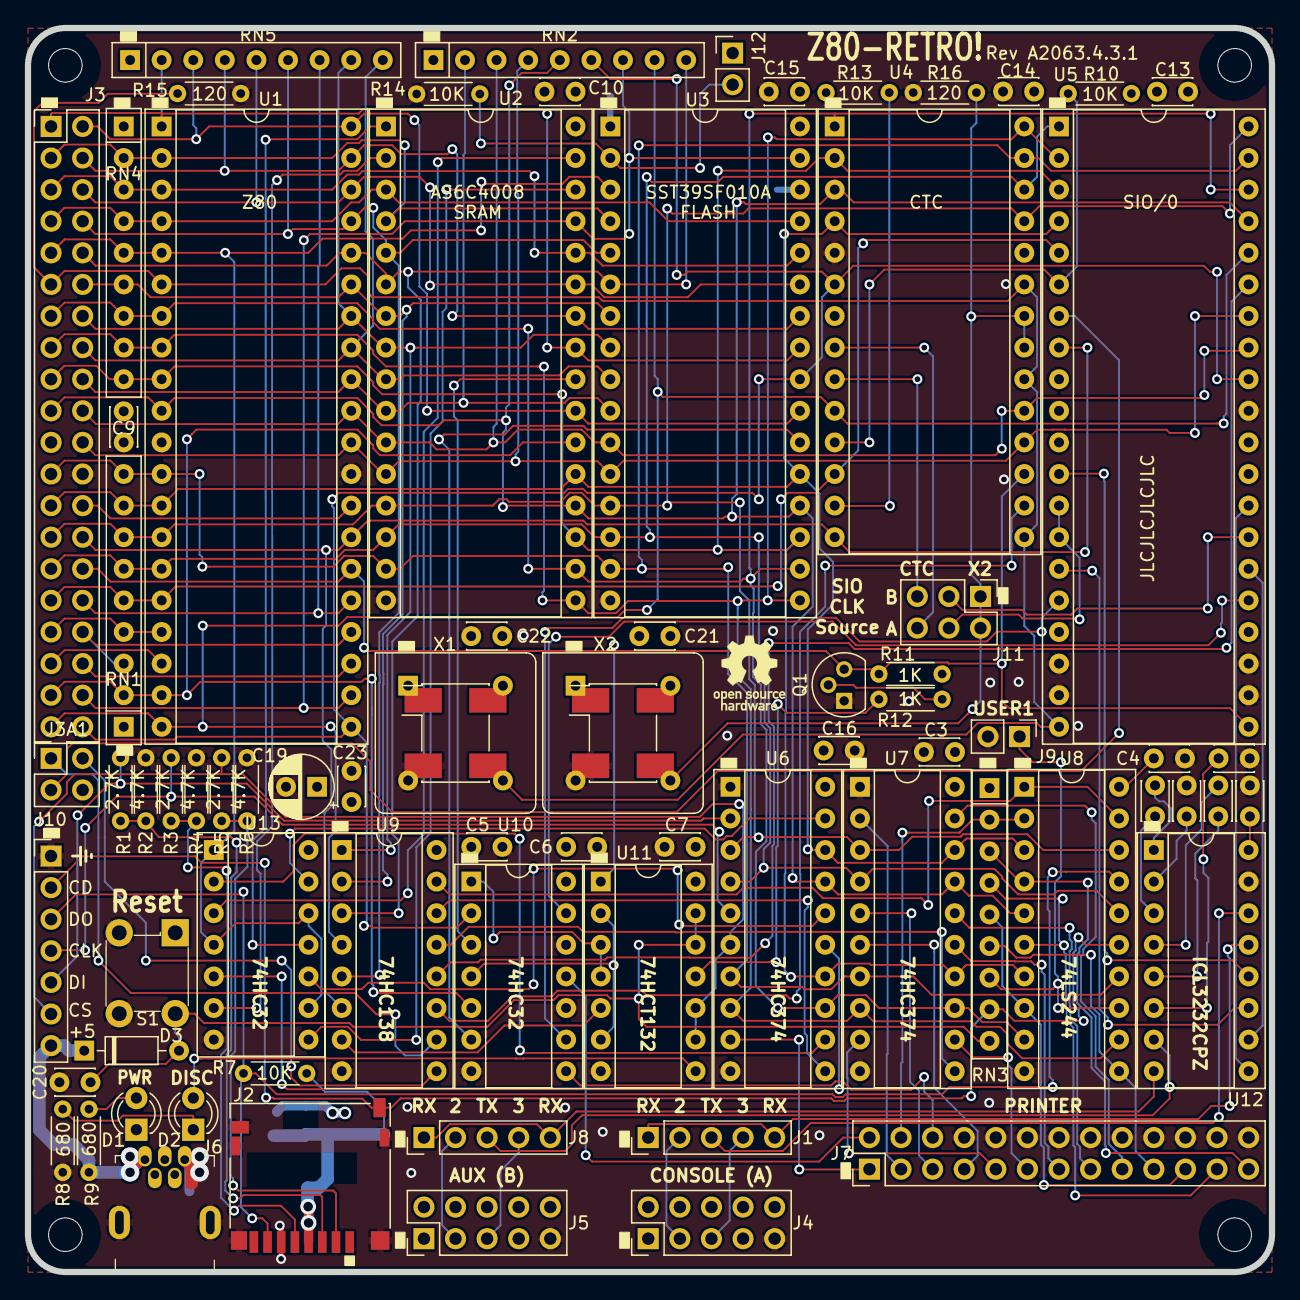
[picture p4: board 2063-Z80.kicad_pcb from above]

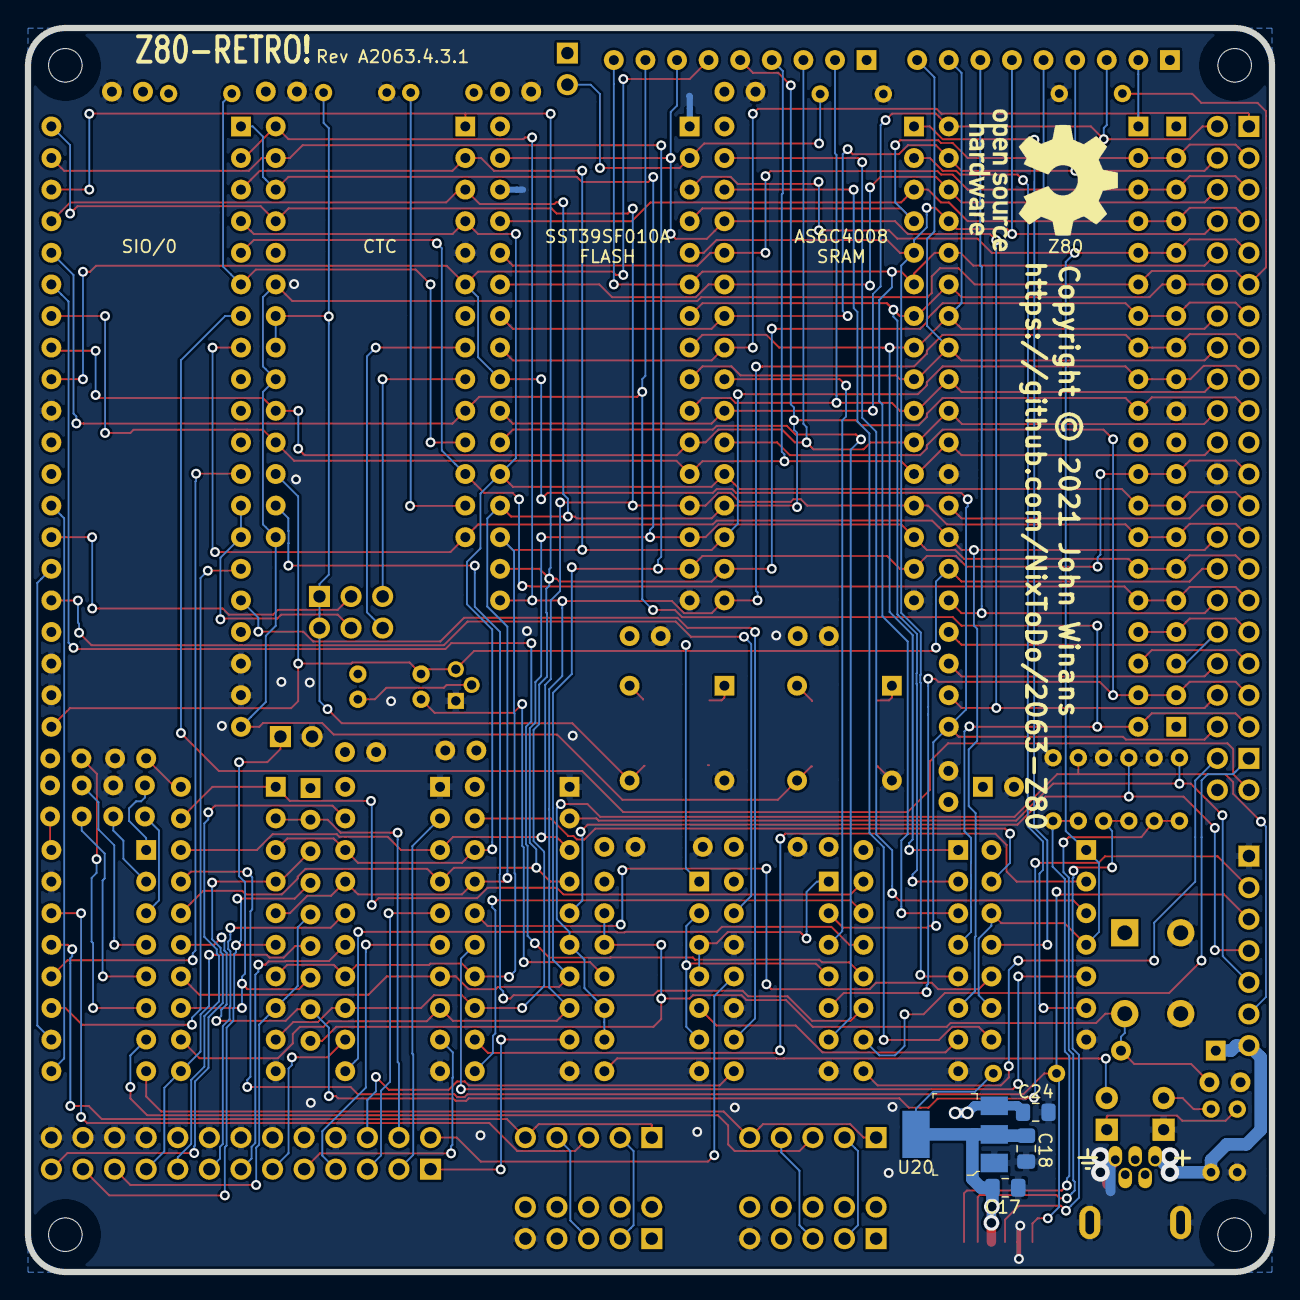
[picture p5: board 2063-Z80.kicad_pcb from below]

Board: 4 copper layers, 100.0 x 100.0 mm, 87 parts (7 on the bottom side), 123 nets.

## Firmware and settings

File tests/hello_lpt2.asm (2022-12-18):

;****************************************************************************
;
;    Copyright (C) 2021 John Winans
;
;    This library is free software; you can redistribute it and/or
;    modify it under the terms of the GNU Lesser General Public
;    License as published by the Free Software Foundation; either
;    version 2.1 of the License, or (at your option) any later version.
;
;    This library is distributed in the hope that it will be useful,
;    but WITHOUT ANY WARRANTY; without even the implied warranty of
;    MERCHANTABILITY or FITNESS FOR A PARTICULAR PURPOSE.  See the GNU
;    Lesser General Public License for more details.
;
;    You should have received a copy of the GNU Lesser General Public
;    License along with this library; if not, write to the Free Software
;    Foundation, Inc., 51 Franklin Street, Fifth Floor, Boston, MA 02110-1301
;    USA
;
;****************************************************************************

; Write gaudy banners to the printer in a loop. 

include 'io.asm'

stacktop:   equ 0   ; end of RAM + 1

    ;###################################################
    ; NOTE THAT THE SRAM IS NOT READABLE AT THIS POINT
    ;###################################################

    ; Select SRAM low bank 0, idle the SD card, and idle printer signals
    ld  a,gpio_out_sd_mosi|gpio_out_sd_ssel|gpio_out_sd_clk|gpio_out_prn_stb
    out (gpio_out),a

    ; Copy the FLASH into the SRAM by reading every byte and 
    ; writing it back into the same address.
    ld  hl,0
    ld  de,0
    ld  bc,_end
    ldir

    ; Disable the FLASH and run from SRAM only from this point on.
    in  a,(flash_disable)   ; Dummy-read this port to disable the FLASH.

    ;###################################################
    ; STARTING HERE, WE ARE RUNNING FROM RAM
    ;###################################################

    ld      sp,stacktop

    call    sioa_init
    call    lpt_init

    ld      hl,rx80_compress
    ld      bc,rx80_compress_len
    call    print_str

waste_paper:
    ld      hl,msg
    ld      bc,msg_len
    call    print_str
    jp      waste_paper


halt_loop:
    halt
    jp      halt_loop


rx80_compress:
    db  0x0f
rx80_compress_len:  equ $-rx80_compress



msg:

if 0
    db  "               ________   ___    ____      _             _   ____       _       _              _____         _                 \r\n"
    db  "              |__  ( _ ) / _ \\  |  _ \\ ___| |_ _ __ ___ | | |  _ \\ _ __(_)_ __ | |_ ___ _ __  |_   _|__  ___| |_               \r\n"
    db  " _____ _____    / // _ \\| | | | | |_) / _ \\ __| '__/ _ \\| | | |_) | '__| | '_ \\| __/ _ \\ '__|   | |/ _ \\/ __| __|  _____ _____ \r\n"
    db  "|_____|_____|  / /| (_) | |_| | |  _ <  __/ |_| | | (_) |_| |  __/| |  | | | | | ||  __/ |      | |  __/\\__ \\ |_  |_____|_____|\r\n"
    db  "              /____\\___/ \\___/  |_| \\_\\___|\\__|_|  \\___/(_) |_|   |_|  |_|_| |_|\\__\\___|_|      |_|\\___||___/\\__|              \r\n"
    db  "\r\n"
endif

if 0
    db  "\r\n"
    db  "#######  #####    ###      ######                             ###    ######                           #######                     \r\n"
    db  "     #  #     #  #   #     #     # ###### ##### #####   ####  ###    #     # #####  # #    # #####       #    ######  ####  ##### \r\n"
    db  "    #   #     # #     #    #     # #        #   #    # #    # ###    #     # #    # # ##   #   #         #    #      #        #   \r\n"
    db  "   #     #####  #     #    ######  #####    #   #    # #    #  #     ######  #    # # # #  #   #         #    #####   ####    #   \r\n"
    db  "  #     #     # #     #    #   #   #        #   #####  #    #        #       #####  # #  # #   #         #    #           #   #   \r\n"
    db  " #      #     #  #   #     #    #  #        #   #   #  #    # ###    #       #   #  # #   ##   #         #    #      #    #   #   \r\n"
    db  "#######  #####    ###      #     # ######   #   #    #  ####  ###    #       #    # # #    #   #         #    ######  ####    #   \r\n"
    db  "\r\n"
endif

if 1
    ; Mostly overstrike to exercise the print carriage w/o wasting paper.
    db  "\r"
    db  "#######  #####    ###      ######                             ###    ######                           #######                     \r"
    db  "     #  #     #  #   #     #     # ###### ##### #####   ####  ###    #     # #####  # #    # #####       #    ######  ####  ##### \r"
    db  "    #   #     # #     #    #     # #        #   #    # #    # ###    #     # #    # # ##   #   #         #    #      #        #   \r"
    db  "   #     #####  #     #    ######  #####    #   #    # #    #  #     ######  #    # # # #  #   #         #    #####   ####    #   \r"
    db  "  #     #     # #     #    #   #   #        #   #####  #    #        #       #####  # #  # #   #         #    #           #   #   \r"
    db  " #      #     #  #   #     #    #  #        #   #   #  #    # ###    #       #   #  # #   ##   #         #    #      #    #   #   \r"
    db  "#######  #####    ###      #     # ######   #   #    #  ####  ###    #       #    # # #    #   #         #    ######  ####    #   \r"
    db  "\r\n"
endif
if 1
    db  "\r..............."
    db  "\r               ..............."
    db  "\r---------------"
    db  "\r               ---------------"
    db  "\r_______________"
    db  "\r               _______________"
    db  "\r!!!!!!!!!!!!!!!"
    db  "\r               !!!!!!!!!!!!!!!"
    db  "\r<<<<<<<<<<<<<<<"
    db  "\r               <<<<<<<<<<<<<<<"
    db  "\r>>>>>>>>>>>>>>>"
    db  "\r               >>>>>>>>>>>>>>>"
    db  "\r000000000000000"
    db  "\r               000000000000000"
    db  "\r#########"
    db  "\r000000000"
    db  "\r@@@@@@@@@"
    db  "\r\n"
endif
msg_len: equ $-msg

;#############################################################################
; Write BC bytes from memory at address in HL
;#############################################################################
print_str:
    push    bc
    ld      c,(hl)
    call    lpt_tx
    inc     hl
    pop     bc
    dec     bc
    ld      a,b
    or      c
    jr      nz,print_str
    ret


include 'lpt.asm'
include 'sio.asm'
include 'hexdump.asm'

;#############################################################################
; A copy of the state of the GPIO output port
;#############################################################################
gpio_out_cache:
    db  gpio_out_sd_mosi|gpio_out_sd_ssel|gpio_out_sd_clk|gpio_out_prn_stb

_end:

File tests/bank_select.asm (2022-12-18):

;****************************************************************************
;
;    Copyright (C) 2021 John Winans
;
;    This library is free software; you can redistribute it and/or
;    modify it under the terms of the GNU Lesser General Public
;    License as published by the Free Software Foundation; either
;    version 2.1 of the License, or (at your option) any later version.
;
;    This library is distributed in the hope that it will be useful,
;    but WITHOUT ANY WARRANTY; without even the implied warranty of
;    MERCHANTABILITY or FITNESS FOR A PARTICULAR PURPOSE.  See the GNU
;    Lesser General Public License for more details.
;
;    You should have received a copy of the GNU Lesser General Public
;    License along with this library; if not, write to the Free Software
;    Foundation, Inc., 51 Franklin Street, Fifth Floor, Boston, MA 02110-1301
;    USA
;
;****************************************************************************

; A test proggie to test the bank select logic & SRAM 

include 'io.asm'

stacktop:   equ 0   ; end of RAM + 1


    jp      _start          ; jump into the HI-bank of memory
    ds      0x8000-$,0xff   ; push the remaining code into the high-bank


    ;###################################################
    ; NOTE THAT THE SRAM IS NOT READABLE AT THIS POINT
    ;###################################################
_start:
    ; Select SRAM low bank 0, idle the SD card, and idle printer signals
    ld      a,(gpio_out_cache)
    out     (gpio_out),a

    ; Copy the FLASH into the SRAM by reading every byte and 
    ; writing it back into the same address.
    ld      hl,0
    ld      de,0
    ld      bc,_end
    ldir

    ; Disable the FLASH and run from SRAM only from this point on.
    in  a,(flash_disable)   ; Dummy-read this port to disable the FLASH.

    ;###################################################
    ; STARTING HERE, WE ARE RUNNING FROM RAM
    ;###################################################

    ld      sp,stacktop

    ; padd the stack with some recognizable data
    ld      hl,0xff00
    ld      (hl),0xaa
    ld      de,0xff01
    ld      bc,0xff
    ldir

    call    sioa_init           ; bring the SIO on line

    ; Print a message indicating the program is running
    ld      hl,startup_msg
    call    puts


    ; NOTE: This code is running in the HI-bank of RAM, so it is OK to
    ; change the menory that appears in the LO-bank here.

    ld      c,0x00              ; Set the SRAM to bank 0
    call    select_bank         ; Set A15-A18 to 0
    call    fill_lo_bank        ; fill 0x0000-0x7fff with 0x00

    ld      c,0x10
    call    select_bank         ; Set A15-A18 to 0x10 (bank 1)
    call    fill_lo_bank        ; fill 0x0000-0x7fff with 0x10

    ld      c,0x20
    call    select_bank         ; Set A15-A18 to 0x10 (bank 2)
    call    fill_lo_bank        ; fill 0x0000-0x7fff with 0x20

    ld      c,0xe0
    call    select_bank         ; Set A15-A18 to 0xe0 (bank 14)
    call    fill_lo_bank        ; fill 0x0000-0x7fff with 0xe0

    ld      c,0x00
    call    dump_bank           ; Select bank 0 and dump its contents
    ld      c,0x10
    call    dump_bank           ; Select bank 1 and dump its contents
    ld      c,0x20
    call    dump_bank           ; Select bank 2 and dump its contents
    ld      c,0x30
    call    dump_bank           ; Select bank 3 and dump what should be garbage
    ld      c,0xe0
    call    dump_bank           ; Select bank 14 and dump its contents
    ld      c,0xf0
    call    dump_bank           ; Bank 15 executable code followed by the stack data


halt_loop:
    halt
    jp      halt_loop


startup_msg:
    db      "\r\n\nlo-bank test.\r\n\0"

dots:
    db      "..."       ; make sure this runs into the crlf below!
crlf:
    db      "\r\n\0"

bank_msg:
    db      "\r\nbank \0"


;#############################################################################
; Dump the bank in the C register
;#############################################################################
dump_bank:
    push    af
    push    hl
    push    bc
    call    select_bank

    ld      hl,bank_msg
    call    puts
    ld      a,c
    call    hexdump_a
    ld      hl,crlf
    call    puts

    ld      hl,0
    ld      bc,0x30
    ld      e,1
    call    hexdump
    ld      hl,dots
    call    puts
    ld      hl,0x7fd0
    ld      bc,0x30
    ld      e,1
    call    hexdump
    pop     bc
    pop     hl
    pop     af
    ret

;#############################################################################
; FIll the low bank of RAM with the value in C
; Clobbers nothing
;#############################################################################
fill_lo_bank:
    push    hl
    push    de
    push    bc
    ld      hl,0
    ld      (hl),c
    ld      de,1
    ld      bc,0x7fff
    ldir
    pop     bc
    pop     de
    pop     hl
    ret

;#############################################################################
; Select the LO memory bank given by the value in C (must be 0x00, 0x10..0xf0)
; Clobbers nothing
;#############################################################################
select_bank:
    push    af
    ld      a,(gpio_out_cache)
    and     0x0f
    or      c
    ld      (gpio_out_cache),a
    out     (gpio_out),a
    pop     af
    ret

include 'puts.asm'
include 'sio.asm'
include 'hexdump.asm'

;#############################################################################
; A copy of the state of the GPIO output port
;#############################################################################
gpio_out_cache:
    db  gpio_out_sd_mosi|gpio_out_sd_ssel|gpio_out_sd_clk|gpio_out_prn_stb

_end:

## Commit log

2022-11-23 Added / Changed my PCB changes.
    [2063-Z80-B_Cu.gbl, 2063-Z80-B_Mask.gbs, 2063-Z80-B_Paste.gbp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]
2022-12-18 Modified to fit my needs.
    [2063-Z80-B_Cu.gbl, 2063-Z80-B_Mask.gbs, 2063-Z80-B_Paste.gbp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]

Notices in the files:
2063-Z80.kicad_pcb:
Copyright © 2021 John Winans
